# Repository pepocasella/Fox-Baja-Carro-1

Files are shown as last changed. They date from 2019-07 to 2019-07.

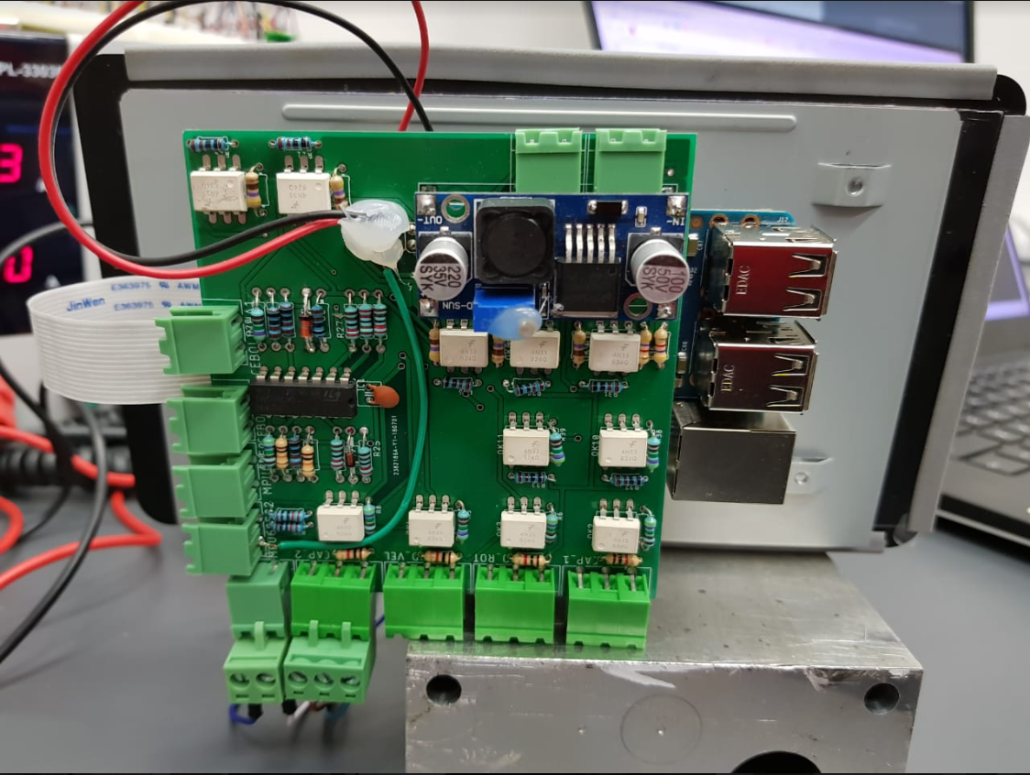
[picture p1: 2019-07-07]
foto_circuito.PNG

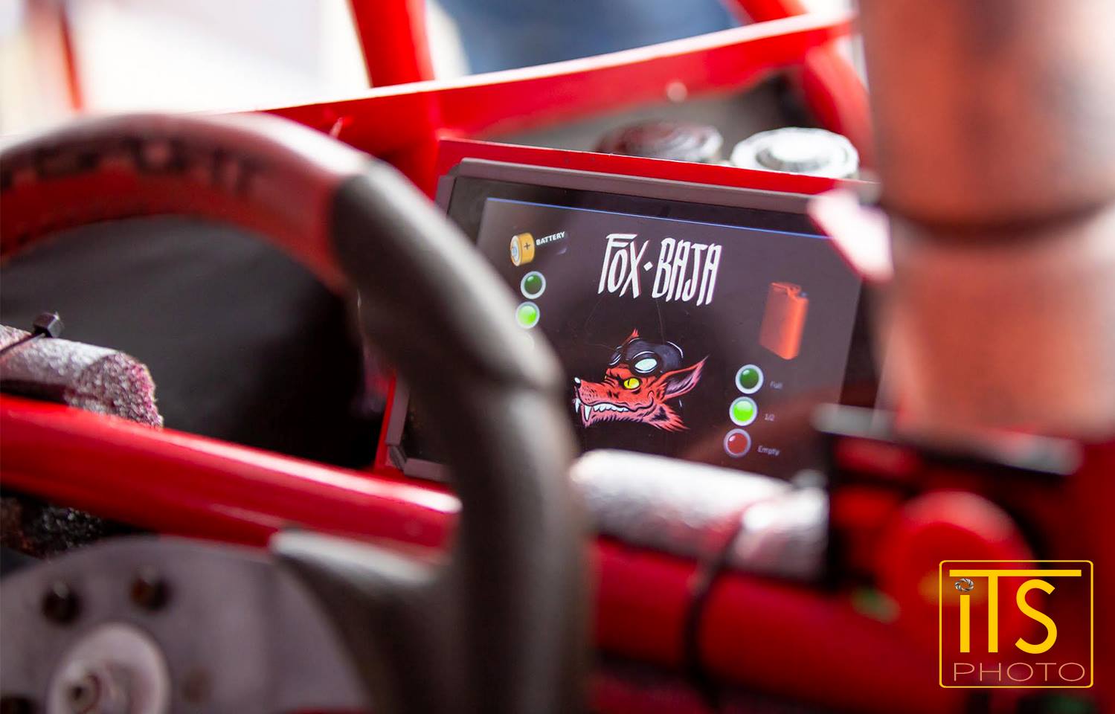
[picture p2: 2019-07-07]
foto_IHM.jpg

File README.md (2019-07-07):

# Fox-Baja-Carro-1
Projeto Elétrica: primeiro projeto da elétrica do fox baja IHM com raspberry pi 3 e tela Lcd 7 Oficial Raspberry Pi 800x480 Touch Screen 

foto_circuito
foto_IHM

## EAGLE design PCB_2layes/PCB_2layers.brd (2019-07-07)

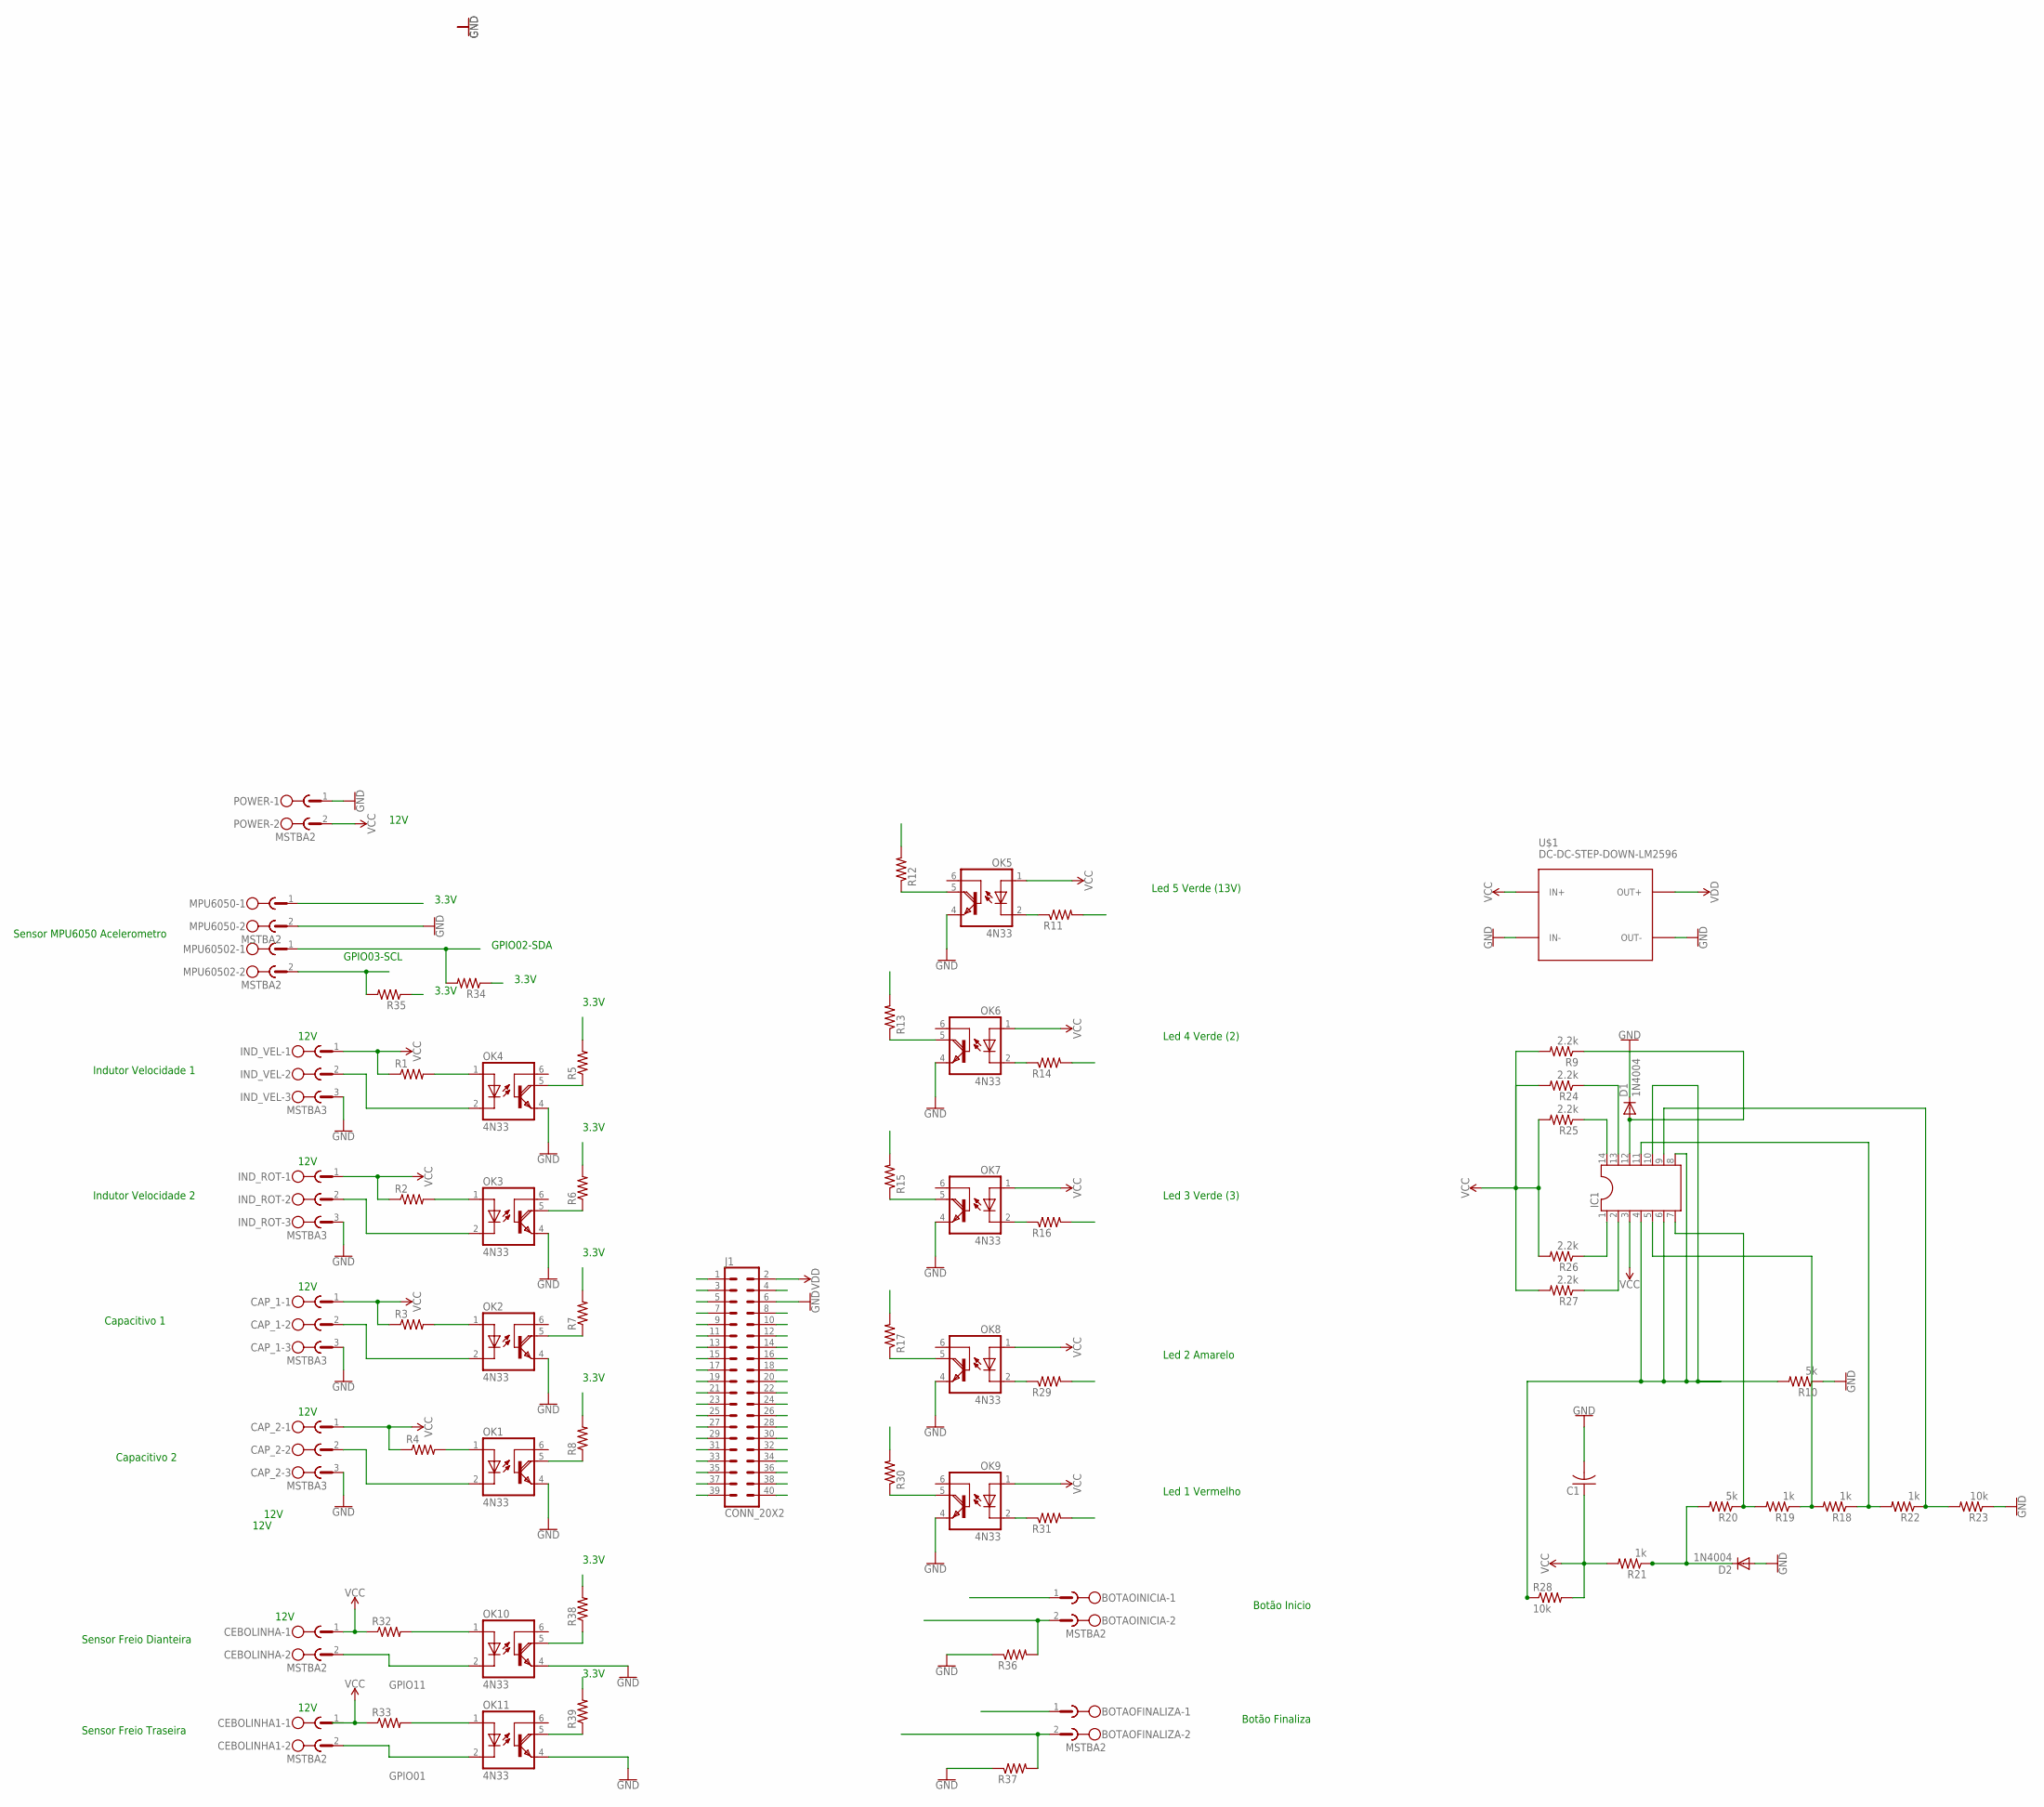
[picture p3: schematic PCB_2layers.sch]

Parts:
BOTAOFINALIZA: MSTBA2
BOTAOINICIA: MSTBA2
C1: C-US025-050X050; C025-050X050
CAP_1, CAP_2: MSTBA3
CEBOLINHA, CEBOLINHA1: MSTBA2
D1, D2: 1N4004; DO41-10
IC1: DIL14
IND_ROT: MSTBA3
IND_VEL: MSTBA3
J1: CONN_20X2; 2X20
MPU6050, MPU60502: MSTBA2
OK1, OK2, OK3, OK4, OK5, OK6, OK7, OK8, OK9, OK10, OK11: 4N33; DIL06
POWER: MSTBA2
R1, R2, R3, R4, R5, R6, R7, R8, R11, R12, R13, R14, R15, R16, R17, R29, R30, R31, R32, R33, R34, R35, R36, R37, R38, R39: R-US_0204/7; 0204/7
R9, R24, R25, R26, R27: 2.2k; 0207/10
R10, R20: 5k; 0207/10
R18, R19, R21, R22: 1k; 0207/10
R23, R28: 10k; 0207/10
U$1: DC-DC-STEP-DOWN-LM2596

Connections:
DC3.3V: BOTAOFINALIZA.1, BOTAOINICIA.1, J1.1, J1.17, MPU6050.1, R5.2, R6.2, R7.2, R8.2, R12.2, R13.2, R15.2, R17.2, R30.2, R34.1, R35.1, R38.2, R39.2
GND: C1.2, CAP_1.3, CAP_2.3, D1.C, D2.A, IND_ROT.3, IND_VEL.3, J1.6, J1.9, J1.14, J1.20, J1.25, J1.30, J1.34, OK1.4 (E), OK2.4 (E), OK3.4 (E), OK4.4 (E), OK5.4 (E), OK6.4 (E), OK7.4 (E), OK8.4 (E), OK9.4 (E), OK10.4 (E), OK11.4 (E), POWER.1, R10.1, R23.1, R36.1, R37.1, U$1.IN-, U$1.OUT-
GPIO01: CEBOLINHA1.2, OK11.2 (C)
GPIO02: J1.3
GPIO2: MPU60502.2, R35.2
GPIO03: J1.5, MPU60502.1, R34.2
GPIO04: J1.7, OK4.5 (COL), R5.1
GPIO05: J1.29
GPIO06: J1.31
GPIO07: J1.26
GPIO08: J1.24
GPIO09: J1.21
GPIO10: J1.19, OK1.5 (COL), R8.1
GPIO11: CEBOLINHA.2, J1.23, OK10.2 (C)
GPIO12: J1.32
GPIO13: J1.33
GPIO14: J1.8, OK5.5 (COL), R12.1
GPIO15: J1.10, OK6.5 (COL), R13.1
GPIO16: BOTAOINICIA.2, J1.36, R36.2
GPIO17: J1.11, OK3.5 (COL), R6.1
GPIO18: J1.12, OK7.5 (COL), R15.1
GPIO19: J1.35, OK10.5 (COL), R38.1
GPIO20: BOTAOFINALIZA.2, J1.38, R37.2
GPIO21: J1.40
GPIO22: J1.15, OK2.5 (COL), R7.1
GPIO23: J1.16, OK8.5 (COL), R17.1
GPIO24: J1.18, OK9.5 (COL), R30.1
GPIO25: J1.22
GPIO26: J1.37, OK11.5 (COL), R39.1
GPIO27: J1.13
ID_SC: J1.28
ID_SD: J1.27
LM339P1: IC1.1, R11.2, R26.1
LM339P2: IC1.2, R14.2, R27.1
LM339P12: R31.2
LM339P13: IC1.13, R16.2, R24.1
LM339P14: IC1.14, R25.1, R29.2
LM33912: D1.A, IC1.12, R9.1
unnamed: IND_ROT.2, OK3.2 (C)
unnamed: CAP_2.2, OK1.2 (C)
unnamed: CAP_1.2, OK2.2 (C)
unnamed: OK3.1 (A), R2.2
unnamed: OK2.1 (A), R3.2
unnamed: OK1.1 (A), R4.2
unnamed: OK4.1 (A), R1.2
unnamed: IND_VEL.2, OK4.2 (C)
unnamed: D2.C, R20.2, R21.1
unnamed: IC1.9, R22.1, R23.2
unnamed: IC1.4, IC1.6, IC1.8, IC1.10, R10.2, R28.1
unnamed: IC1.5, R18.2, R19.1
unnamed: IC1.11, R18.1, R22.2
unnamed: IC1.7, R19.2, R20.1
unnamed: OK5.2 (C), R11.1
unnamed: OK6.2 (C), R14.1
unnamed: OK10.1 (A), R32.2
unnamed: OK7.2 (C), R16.1
unnamed: OK8.2 (C), R29.1
unnamed: OK9.2 (C), R31.1
unnamed: OK11.1 (A), R33.2
VCC: C1.1, CAP_1.1, CAP_2.1, CEBOLINHA.1, CEBOLINHA1.1, IC1.3, IND_ROT.1, IND_VEL.1, OK5.1 (A), OK6.1 (A), OK7.1 (A), OK8.1 (A), OK9.1 (A), POWER.2, R1.1, R2.1, R3.1, R4.1, R9.2, R21.2, R24.2, R25.2, R26.2, R27.2, R28.2, R32.1, R33.1, U$1.IN+
VDD: J1.2, J1.4, U$1.OUT+

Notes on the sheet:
Indutor Velocidade 1
Indutor Velocidade 2
Capacitivo 1
Capacitivo 2
Led 5 Verde (13V)
Sensor Freio Dianteira
Sensor MPU6050 Acelerometro
Sensor Freio Traseira
Led 4 Verde (2)
Botão Inicio
Botão Finaliza
Led 3 Verde (3)
Led 2 Amarelo
Led 1 Vermelho
3.3V
12V
GPIO03-SCL
GPIO02-SDA

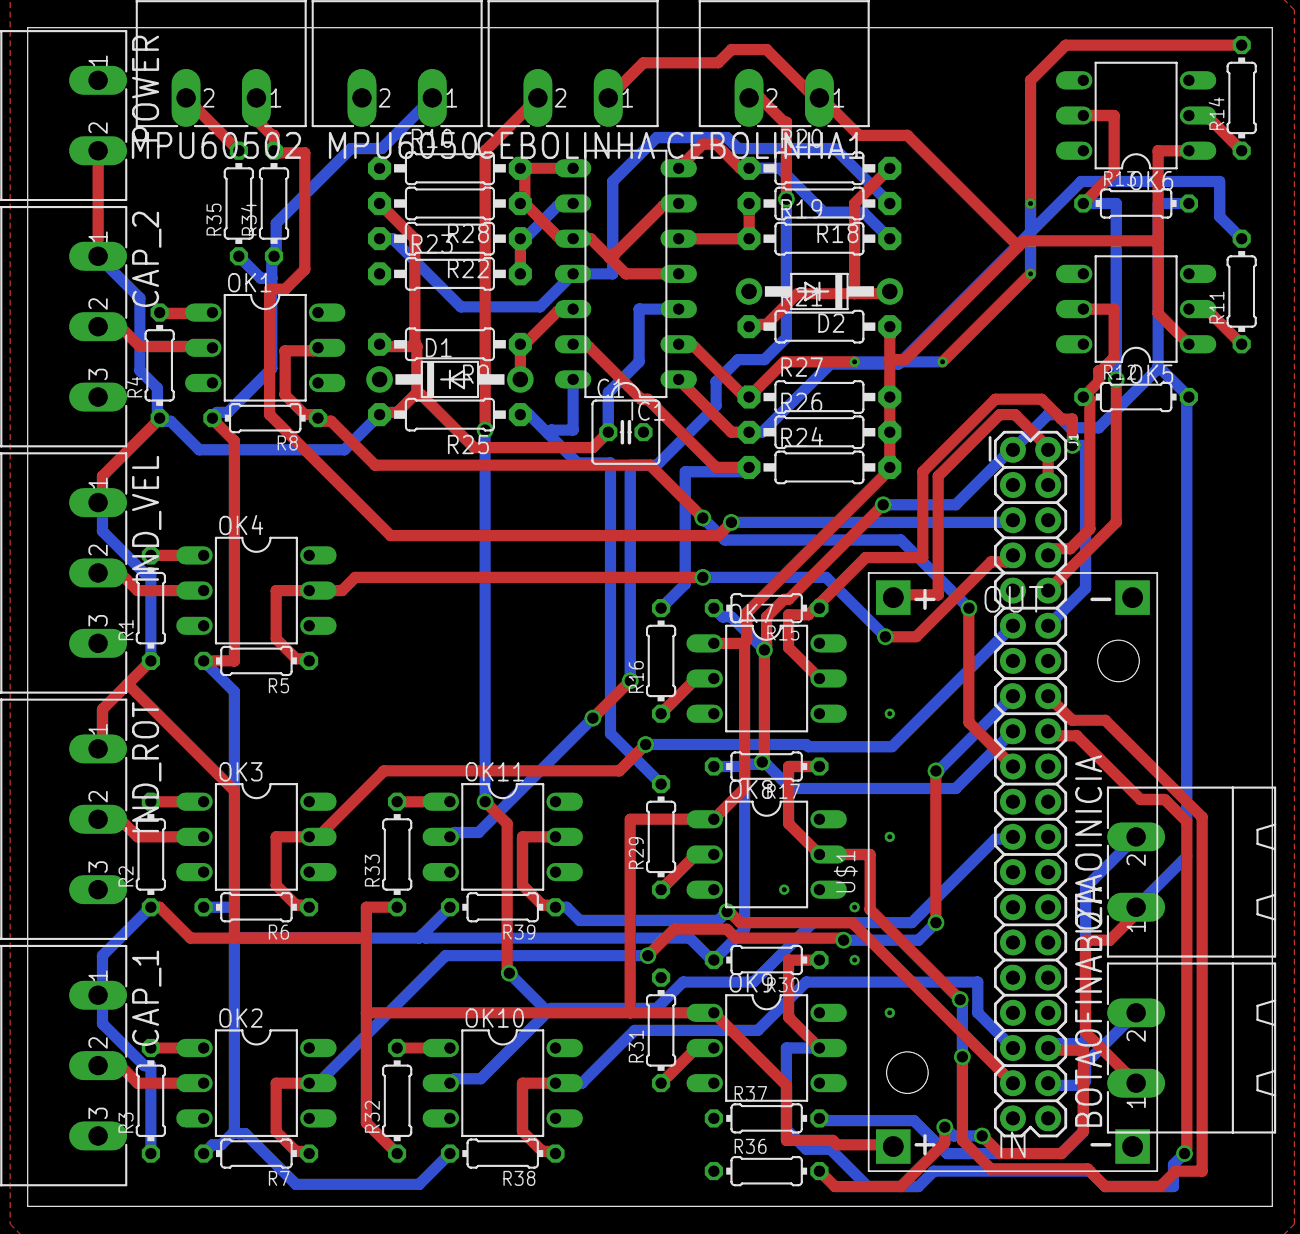
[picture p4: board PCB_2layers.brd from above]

Board: 2 copper layers, 89.8 x 85.1 mm, 67 parts (0 on the bottom side), 47 nets.

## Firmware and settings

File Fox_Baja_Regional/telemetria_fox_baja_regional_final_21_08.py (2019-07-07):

# -*- coding: utf-8 -*-
"""
Created on Thu Aug 16 16:24:30 2018

@author: Pedro Casella
"""

"""Imports"""
from datetime import datetime
import RPi.GPIO as GPIO
from PyQt5 import QtCore, QtGui, QtWidgets
import time


from PyQt5.QtGui import*
from PyQt5.QtWidgets import*
from PyQt5.QtCore import*

"""Setup Pinos RaspBerry Pi 3"""

#Sensor Bateria GPIOs
pinoBat_led_verde_3 = 14
pinoBat_led_verde_2 = 15
pinoBat_led_verde_1 = 18
pinoBat_led_amarelo = 23
pinoBat_led_vermelho = 24

GPIO.setmode(GPIO.BCM)
GPIO.setup(pinoBat_led_verde_1, GPIO.IN, pull_up_down = GPIO.PUD_DOWN)
GPIO.setmode(GPIO.BCM)
GPIO.setup(pinoBat_led_verde_2, GPIO.IN, pull_up_down = GPIO.PUD_DOWN)
GPIO.setmode(GPIO.BCM)
GPIO.setup(pinoBat_led_verde_3, GPIO.IN, pull_up_down = GPIO.PUD_DOWN)
GPIO.setmode(GPIO.BCM)
GPIO.setup(pinoBat_led_amarelo, GPIO.IN, pull_up_down = GPIO.PUD_DOWN)
GPIO.setmode(GPIO.BCM)
GPIO.setup(pinoBat_led_vermelho, GPIO.IN, pull_up_down = GPIO.PUD_DOWN)

#Sensor Gasolina GPIOs
pinoGas_led_verde_1 = 22
pinoGas_led_verde_2 = 10
#pinoBat_led_vermelho = 

GPIO.setmode(GPIO.BCM)
GPIO.setup(pinoGas_led_verde_1, GPIO.IN, pull_up_down = GPIO.PUD_DOWN)
GPIO.setmode(GPIO.BCM)
GPIO.setup(pinoGas_led_verde_2, GPIO.IN, pull_up_down = GPIO.PUD_DOWN)
#GPIO.setmode(GPIO.BCM)
#GPIO.setup(pinoGas_led_vermelho, GPIO.IN, pull_up_down = GPIO.PUD_DOWN)

    

class Ui_MainWindow(object):
    def setupUi(self, MainWindow):
        MainWindow.setObjectName("MainWindow")
        MainWindow.resize(800, 480)
        MainWindow.setStyleSheet("\n"
"background-color: rgb(0, 0, 0);")
        self.centralwidget = QtWidgets.QWidget(MainWindow)
        self.centralwidget.setObjectName("centralwidget")
        self.label_4 = QtWidgets.QLabel(self.centralwidget)
        self.label_4.setGeometry(QtCore.QRect(110, 310, 53, 53))
        self.label_4.setText("")
        self.label_4.setPixmap(QtGui.QPixmap("led_laranja_apagado.png"))
        self.label_4.setObjectName("label_4")
        self.label_3 = QtWidgets.QLabel(self.centralwidget)
        self.label_3.setGeometry(QtCore.QRect(110, 370, 53, 53))
        self.label_3.setText("")
        self.label_3.setPixmap(QtGui.QPixmap("led_vermelho_apagado.png"))
        self.label_3.setObjectName("label_3")
        self.label_6 = QtWidgets.QLabel(self.centralwidget)
        self.label_6.setGeometry(QtCore.QRect(110, 190, 53, 53))
        self.label_6.setText("")
        self.label_6.setPixmap(QtGui.QPixmap("led_verde_apagado.png"))
        self.label_6.setObjectName("label_6")
        self.label_7 = QtWidgets.QLabel(self.centralwidget)
        self.label_7.setGeometry(QtCore.QRect(110, 130, 53, 53))
        self.label_7.setText("")
        self.label_7.setPixmap(QtGui.QPixmap("led_verde_apagado.png"))
        self.label_7.setObjectName("label_7")
        self.label_2 = QtWidgets.QLabel(self.centralwidget)
        self.label_2.setGeometry(QtCore.QRect(660, 270, 101, 21))
        self.label_2.setStyleSheet("color: rgb(255, 255, 255);\n"
"font: 75 10pt \"MS Shell Dlg 2\";")
        self.label_2.setObjectName("label_2")
        self.label_14 = QtWidgets.QLabel(self.centralwidget)
        self.label_14.setGeometry(QtCore.QRect(660, 330, 101, 21))
        self.label_14.setStyleSheet("color: rgb(255, 255, 255);\n"
"font: 75 10pt \"MS Shell Dlg 2\";")
        self.label_14.setObjectName("label_14")
        self.label_15 = QtWidgets.QLabel(self.centralwidget)
        self.label_15.setGeometry(QtCore.QRect(660, 390, 101, 21))
        self.label_15.setStyleSheet("color: rgb(255, 255, 255);\n"
"font: 75 10pt \"MS Shell Dlg 2\";")
        self.label_15.setObjectName("label_15")
        self.label = QtWidgets.QLabel(self.centralwidget)
        self.label.setGeometry(QtCore.QRect(270, 30, 246, 128))
        self.label.setText("")
        self.label.setPixmap(QtGui.QPixmap("../Projeto_Python_Baja/IHM/logo_fox_baja.png"))
        self.label.setObjectName("label")
        self.label_11 = QtWidgets.QLabel(self.centralwidget)
        self.label_11.setGeometry(QtCore.QRect(250, 190, 283, 229))
        self.label_11.setText("")
        self.label_11.setPixmap(QtGui.QPixmap("../Projeto_Python_Baja/IHM/mascote_fox_baja.png"))
        self.label_11.setObjectName("label_11")
        self.label_16 = QtWidgets.QLabel(self.centralwidget)
        self.label_16.setGeometry(QtCore.QRect(70, 30, 124, 94))
        self.label_16.setText("")
        self.label_16.setPixmap(QtGui.QPixmap("battery_icon_2.png"))
        self.label_16.setObjectName("label_16")
        self.label_17 = QtWidgets.QLabel(self.centralwidget)
        self.label_17.setGeometry(QtCore.QRect(620, 90, 87, 140))
        self.label_17.setText("")
        self.label_17.setPixmap(QtGui.QPixmap("gas_icon.png"))
        self.label_17.setObjectName("label_17")
        self.label_12 = QtWidgets.QLabel(self.centralwidget)
        self.label_12.setGeometry(QtCore.QRect(590, 370, 53, 53))
        self.label_12.setText("")
        self.label_12.setPixmap(QtGui.QPixmap("led_vermelho_apagado.png"))
        self.label_12.setObjectName("label_12")
        self.label_13 = QtWidgets.QLabel(self.centralwidget)
        self.label_13.setGeometry(QtCore.QRect(590, 250, 53, 53))
        self.label_13.setText("")
        self.label_13.setPixmap(QtGui.QPixmap("led_verde_apagado.png"))
        self.label_13.setObjectName("label_13")
        self.label_18 = QtWidgets.QLabel(self.centralwidget)
        self.label_18.setGeometry(QtCore.QRect(590, 310, 53, 53))
        self.label_18.setText("")
        self.label_18.setPixmap(QtGui.QPixmap("led_verde_apagado.png"))
        self.label_18.setObjectName("label_18")
        self.label_5 = QtWidgets.QLabel(self.centralwidget)
        self.label_5.setGeometry(QtCore.QRect(110, 250, 53, 53))
        self.label_5.setText("")
        self.label_5.setPixmap(QtGui.QPixmap("led_verde_apagado.png"))
        self.label_5.setObjectName("label_5")
        MainWindow.setCentralWidget(self.centralwidget)
        self.menubar = QtWidgets.QMenuBar(MainWindow)
        self.menubar.setGeometry(QtCore.QRect(0, 0, 800, 26))
        self.menubar.setObjectName("menubar")
        MainWindow.setMenuBar(self.menubar)
        self.statusbar = QtWidgets.QStatusBar(MainWindow)
        self.statusbar.setObjectName("statusbar")
        MainWindow.setStatusBar(self.statusbar)

        self.retranslateUi(MainWindow)
        QtCore.QMetaObject.connectSlotsByName(MainWindow)

        self.counter =1
        self.timer = QTimer()
        self.timer.setInterval(500)
        self.timer.timeout.connect(self.recurring_timer)
        self.timer.start()



    '''
    pinoBat_led_verde_3 = 14
    pinoBat_led_verde_2 = 15
    pinoBat_led_verde_1 = 18
    pinoBat_led_amarelo = 23
    pinoBat_led_vermelho = 24

    pinoGas_led_verde_1 = 22
    pinoBat_led_verde_2 = 10
    '''

    '''
    label_3 = Bat_led_vermelho
    label_4 = Bat_led_amarelo
    label_5 = Bat_led_verde_1
    label_5 = Bat_led_verde_2
    label_6 = Bat_led_verde_3

    label_7 = Gas_led_verde_2
    label_8 = Gas_led_verde_1
    label_9 = Gas_led_vermelho_empty
    '''
 def recurring_timer(self):

        #loop check bateria
        if GPIO.input(14) == GPIO.HIGH:
            print('Bat_led_verde_3 - apagado')
            self.label_7.setPixmap(QtGui.QPixmap("led_verde_apagado.png"))
        else:
        #elif GPIO.input(14) == GPIO.LOW:
            print('Bat_led_verde_3 - aceso')
            self.label_7.setPixmap(QtGui.QPixmap("led_verde_aceso.png"))

        if GPIO.input(15) == GPIO.HIGH:
            print('Bat_led_verde_2 - apagado')
            self.label_6.setPixmap(QtGui.QPixmap("led_verde_apagado.png"))
        else:
        #elif GPIO.input(15) == GPIO.LOW:
            print('Bat_led_verde_2 - aceso')
            self.label_6.setPixmap(QtGui.QPixmap("led_verde_aceso.png"))

        if GPIO.input(18) == GPIO.HIGH:
            print('Bat_led_verde_1 - apagado')
            self.label_5.setPixmap(QtGui.QPixmap("led_verde_apagado.png"))
        else:
        #elif GPIO.input(18) == GPIO.LOW:
            print('Bat_led_verde_1 - aceso')
            self.label_5.setPixmap(QtGui.QPixmap("led_verde_aceso.png"))

        if GPIO.input(23) == GPIO.HIGH:
            print('Bat_led_amarelo - apagado')
            self.label_4.setPixmap(QtGui.QPixmap("led_laranja_apagado.png"))
        else:
        #elif GPIO.input(23) == GPIO.LOW:
            print('Bat_led_amarelo - aceso')
            self.label_4.setPixmap(QtGui.QPixmap("led_laranja_aceso.png"))

        if GPIO.input(24) == GPIO.HIGH:
            print('Bat_led_vermelho - apagado')
            self.label_3.setPixmap(QtGui.QPixmap("led_vermelho_apagado.png"))
        else:
        #elif GPIO.input(24) == GPIO.LOW:
            print('Bat_led_vermelho - aceso')
            self.label_3.setPixmap(QtGui.QPixmap("led_vermelho_aceso.png"))


        #loop check gasolina
        if GPIO.input(22) == GPIO.HIGH:
            print('Bat_led_verde_2 - aceso')
            self.label_13.setPixmap(QtGui.QPixmap("led_verde_aceso.png"))
        else:
        #elif GPIO.input(22) == GPIO.LOW:
            print('Bat_led_verde_2 - apagado')
            self.label_13.setPixmap(QtGui.QPixmap("led_verde_apagado.png"))

        if GPIO.input(10) == GPIO.HIGH:
            print('Bat_led_verde_1 - aceso')
            self.label_18.setPixmap(QtGui.QPixmap("led_verde_aceso.png"))
        else:
        #elif GPIO.input(10) == GPIO.LOW:
            print('Bat_led_verde_1 - apagado')
            self.label_18.setPixmap(QtGui.QPixmap("led_verde_apagado.png"))

        if GPIO.input(22) or GPIO.input(10):
            print('Bat_led_vermelho - aceso')
            self.label_12.setPixmap(QtGui.QPixmap("led_vermelho_apagado.png"))
        else:
            print('Bat_led_vermelho - apagado')
            self.label_12.setPixmap(QtGui.QPixmap("led_vermelho_aceso.png"))

    def retranslateUi(self, MainWindow):
        _translate = QtCore.QCoreApplication.translate
        MainWindow.setWindowTitle(_translate("MainWindow", "MainWindow"))
        self.label_2.setText(_translate("MainWindow", "Full"))
        self.label_14.setText(_translate("MainWindow", "1/2"))
        self.label_15.setText(_translate("MainWindow", "Empty"))


if __name__ == "__main__":
    import sys
    app = QtWidgets.QApplication(sys.argv)
    MainWindow = QtWidgets.QMainWindow()
    ui = Ui_MainWindow()
    ui.setupUi(MainWindow)
    MainWindow.show()
    sys.exit(app.exec_())

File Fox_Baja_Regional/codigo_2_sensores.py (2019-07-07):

# -*- coding: utf-8 -*-
"""
Created on Thu Jul 26 12:02:44 2018

@author: Pedro Casella
"""
import time
import smbus
import struct

print("inicio")

i2c_address_1 = 0x68 #mpu6050_1
i2c_address_2 = 0x69 #mpu6050_2

sleep_mgmt = 0x6B
accel_x_out = 0x3B
bus = None

#mpu6050_1
acc_x_1 = 0
acc_y_1 = 0
acc_z_1 = 0
temp_1 = 0
gyro_x_1 = 0
gyro_y_1 = 0
gyro_z_1 = 0

#mpu6050_2
acc_x_2 = 0
acc_y_2 = 0
acc_z_2 = 0
temp_2 = 0
gyro_x_2 = 0
gyro_y_2 = 0
gyro_z_2 = 0

teste = 0

lista_acc_x_1 = []
lista_acc_y_1 = []
lista_acc_z_1 = []
lista_temp_1 = []

lista_acc_x_2 = []
lista_acc_y_2 = []
lista_acc_z_2 = []
lista_temp_2 = []




def initmpu():
    global bus
    bus = smbus.SMBus(1)
    bus.write_byte_data(i2c_address_1,sleep_mgmt,0x00)
    bus.write_byte_data(i2c_address_2,sleep_mgmt,0x00)
    
def get_data_1():
    
    #Mcpu6050_1
    global acc_x_1, acc_y_1, acc_z_1, temp_1, gyro_x_1, gyro_y_1, gyro_z_1
    bus.write_byte(i2c_address_1, accel_x_out)
    
    rawdata_1 = ""
    for i in range(14):
        rawdata_1 += chr(bus.read_byte_data(i2c_address_1,accel_x_out+i))
    data_1 = struct.unpack('>hhhhhhh', rawdata_1)
    
    acc_x_1 = data_1[0]/16384.0
    acc_y_1 = data_1[1]/16384.0
    acc_z_1 = data_1[2]/16384.0
    zero_point = -512 - (340*35)
    temp_1 = (data_1[3]-zero_point)/340.0
    
    gyro_x_1 = data_1[4]/131.0
    gyro_y_1 = data_1[5]/131.0
    gyro_z_1 = data_1[6]/131.0
    
    #Mcpu6050_2
    global acc_x_2, acc_y_2, acc_z_2, temp_2, gyro_x_2, gyro_y_2, gyro_z_2
    bus.write_byte(i2c_address_2, accel_x_out)
    
    rawdata_2 = ""
    for i in range(14):
        rawdata_2 += chr(bus.read_byte_data(i2c_address_2,accel_x_out+i))
    data_2 = struct.unpack('>hhhhhhh', rawdata_2)
    
    acc_x_2 = data_2[0]/16384.0
    acc_y_2 = data_2[1]/16384.0
    acc_z_2 = data_2[2]/16384.0
    zero_point = -512 - (340*35)
    temp_2 = (data_2[3]-zero_point)/340.0
    
    gyro_x_2 = data_2[4]/131.0
    gyro_y_2 = data_2[5]/131.0
    gyro_z_2 = data_2[6]/131.0
    
    
def main():
    initmpu()
    while True:
        get_data_1()
        print("Sensor_1 ---- data_1:")
        print("Acc (%.3f,%.3f,%.3f)g," %(acc_x_1,acc_y_1,acc_z_1))
        print("temp %.1f C," %temp_1)
        print("gyro (%.3f,%.3f,%.3f) deg/s" % (gyro_x_1,gyro_y_1,gyro_z_1))
        
        print("Sensor_2 ---- data_2:")
        print("Acc (%.3f,%.3f,%.3f)g," %(acc_x_2,acc_y_2,acc_z_2))
        print("temp %.1f C," %temp_2)
        print("gyro (%.3f,%.3f,%.3f) deg/s" % (gyro_x_2,gyro_y_2,gyro_z_2))
        
        print("Fim")
        time.sleep(0.5)
      
if __name__ == "__main__":
    
    print("Fox Baja")
    
    main()
    
    
    
    
    
    
    
    
    
    

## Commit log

2019-07-07 upload do primeiro projeto do carro baja do Insper. Cógigo em pyhton para raspberry com IHM idealizada. Circuito para aquisição de sinais de nivel do tanque da gasolina, giroscópio e velocidade do mo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
    [PCB_1layer.brd, PCB_1layer.sch, PCB_2layers.brd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]
2019-07-07 upload de fotos

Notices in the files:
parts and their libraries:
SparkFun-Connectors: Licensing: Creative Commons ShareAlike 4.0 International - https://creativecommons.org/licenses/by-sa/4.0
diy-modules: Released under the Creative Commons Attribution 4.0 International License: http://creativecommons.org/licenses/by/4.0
